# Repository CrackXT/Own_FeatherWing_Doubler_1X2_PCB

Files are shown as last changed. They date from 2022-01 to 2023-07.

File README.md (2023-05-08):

# Own_FeatherWing_Doubler_1X2_PCB

PCB files for two Adafruit Feather/FeatherWing on one PCB (side by side)

# Description

Two Feather/FeatherWing can be placed side by side on this board.

The Doubler 1X2, has a tripple duplicate breakout for each pin on a Feather, as well as a bunch of plain grid development holes. Also, the three sets of pins are cross connected and for GND(- or black) and 3.3V(+ or red), they give you a full strip of connected pads.

The board can be produced here (AISLER) with the files (.brd and .sch) or by any other PCB manufacturer. -> https://aisler.net/

# Serie

- .dev

# Layout

Top<br>
1X2_Top

Bottom<br>
1X2_Bottom

Routing/Dimensions(inch)<br>
1X2_v1 0

Schematic<br>
Schematic as .pdf at the top of the page.

# License

The design and layout is based on open source publications from Adafruit and has been modified for side-by-side assembly.

# Thanks!

Great work and many thanks to Adafruit! https://www.adafruit.com/

# Version - Build

v1.0 - 21.01.2022

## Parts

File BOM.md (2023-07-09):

# BOM - List

part list for Use

# socket strips
2x  1X12  https://www.reichelt.de/buchsenleiste-2-54mm-1x12-gerade-bkl-10120951-p266676.html?&trstct=pol_1&nbc=1<br>
2x  1x16  https://www.reichelt.de/buchsenleiste-2-54mm-1x16-gerade-bkl-10120953-p266678.html?&nbc=1<br>

# pin headers
2x  1X12  https://www.reichelt.de/stiftleiste-2-54mm-1x12-h-11-6mm-gerade-bkl-10120916-p262780.html?&trstct=pol_2&nbc=1<br>
2x  1X16  https://www.reichelt.de/stiftleiste-2-54mm-1x16-h-11-6mm-gerade-bkl-10120918-p262782.html?&trstct=pol_2&nbc=1<br>

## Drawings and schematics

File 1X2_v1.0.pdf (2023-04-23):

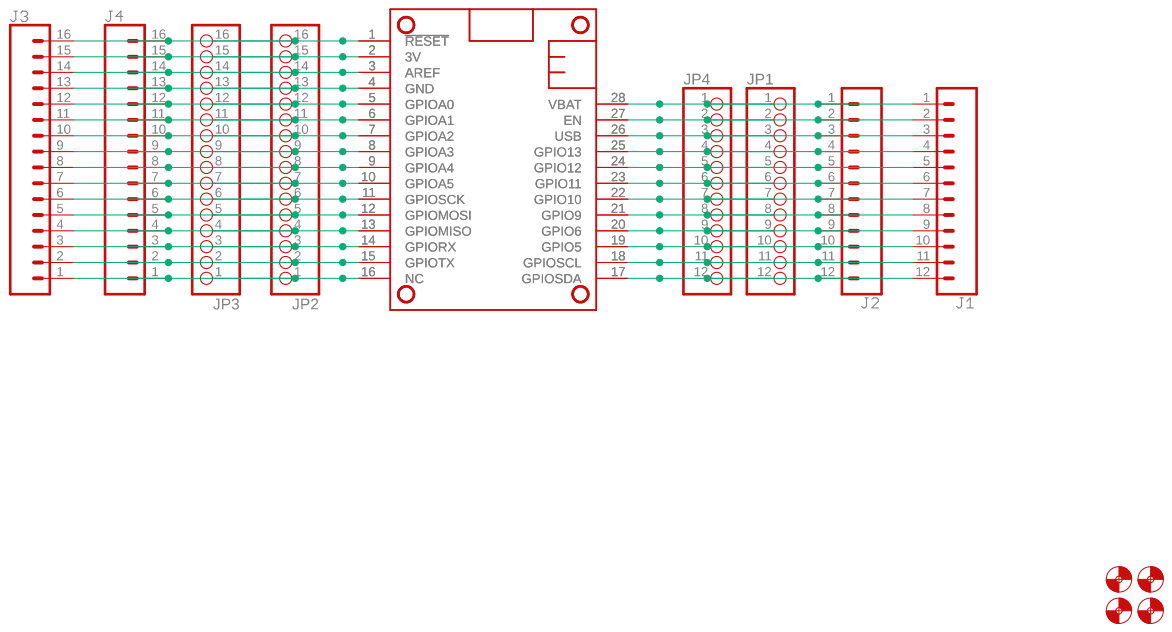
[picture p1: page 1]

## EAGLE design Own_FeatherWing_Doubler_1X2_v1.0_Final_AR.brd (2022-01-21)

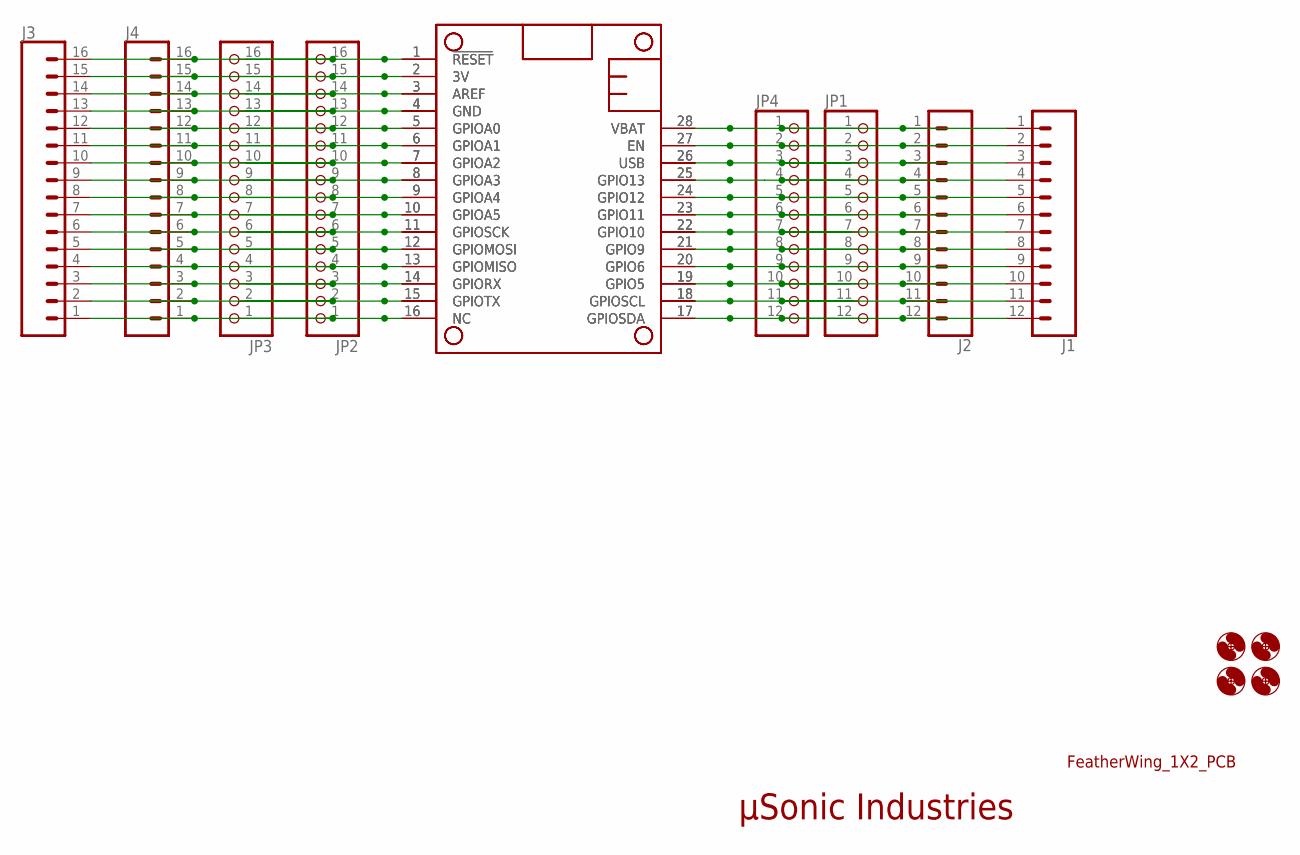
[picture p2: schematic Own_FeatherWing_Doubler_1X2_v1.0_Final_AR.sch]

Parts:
J1, J2: CONN_12NO_SILK; 1X12_NO_SILK
J3, J4: CONN_161X16_NO_SILK; 1X16_NO_SILK
JP1, JP4: HEADER-1X1276MIL; 1X12_ROUND_76MIL
JP2, JP3: HEADER-1X16_76MIL; 1X16_ROUND_76MIL
MS1, MS2: FEATHERWING_NODIM; FEATHERWING_DIM
U$2, U$3, U$4, U$5: MOUNTHOLEBIG; OWN_MOUNTHOLE_BIGAREA

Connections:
3V: J3.15, J4.15, JP2.15, JP3.15, MS1.2 (3V), MS2.2 (3V)
GND: J3.13, J4.13, JP2.13, JP3.13, MS1.4 (GND), MS2.4 (GND)
unnamed: J1.2, J2.2, JP1.2, JP4.2, MS1.27 (EN), MS2.27 (EN)
unnamed: J3.1, J4.1, JP2.1, JP3.1, MS1.16 (NC), MS2.16 (NC)
unnamed: J1.4, J2.4, JP1.4, JP4.4, MS1.25 (GPIO13), MS2.25 (GPIO13)
unnamed: J3.2, J4.2, JP2.2, JP3.2, MS1.15 (GPIOTX), MS2.15 (GPIOTX)
unnamed: J1.5, J2.5, JP1.5, JP4.5, MS1.24 (GPIO12), MS2.24 (GPIO12)
unnamed: J3.3, J4.3, JP2.3, JP3.3, MS1.14 (GPIORX), MS2.14 (GPIORX)
unnamed: J3.4, J4.4, JP2.4, JP3.4, MS1.13 (GPIOMISO), MS2.13 (GPIOMISO)
unnamed: J3.5, J4.5, JP2.5, JP3.5, MS1.12 (GPIOMOSI), MS2.12 (GPIOMOSI)
unnamed: J3.6, J4.6, JP2.6, JP3.6, MS1.11 (GPIOSCK), MS2.11 (GPIOSCK)
unnamed: J3.7, J4.7, JP2.7, JP3.7, MS1.10 (GPIOA5), MS2.10 (GPIOA5)
unnamed: J3.8, J4.8, JP2.8, JP3.8, MS1.9 (GPIOA4), MS2.9 (GPIOA4)
unnamed: J3.9, J4.9, JP2.9, JP3.9, MS1.8 (GPIOA3), MS2.8 (GPIOA3)
unnamed: J3.10, J4.10, JP2.10, JP3.10, MS1.7 (GPIOA2), MS2.7 (GPIOA2)
unnamed: J3.11, J4.11, JP2.11, JP3.11, MS1.6 (GPIOA1), MS2.6 (GPIOA1)
unnamed: J3.12, J4.12, JP2.12, JP3.12, MS1.5 (GPIOA0), MS2.5 (GPIOA0)
unnamed: J3.14, J4.14, JP2.14, JP3.14, MS1.3 (AREF), MS2.3 (AREF)
unnamed: J3.16, J4.16, JP2.16, JP3.16, MS1.1 (!RESET), MS2.1 (!RESET)
unnamed: J1.6, J2.6, JP1.6, JP4.6, MS1.23 (GPIO11), MS2.23 (GPIO11)
unnamed: J1.7, J2.7, JP1.7, JP4.7, MS1.22 (GPIO10), MS2.22 (GPIO10)
unnamed: J1.8, J2.8, JP1.8, JP4.8, MS1.21 (GPIO9), MS2.21 (GPIO9)
unnamed: J1.9, J2.9, JP1.9, JP4.9, MS1.20 (GPIO6), MS2.20 (GPIO6)
unnamed: J1.10, J2.10, JP1.10, JP4.10, MS1.19 (GPIO5), MS2.19 (GPIO5)
unnamed: J1.11, J2.11, JP1.11, JP4.11, MS1.18 (GPIOSCL), MS2.18 (GPIOSCL)
unnamed: J1.12, J2.12, JP1.12, JP4.12, MS1.17 (GPIOSDA), MS2.17 (GPIOSDA)
USB: J1.3, J2.3, JP1.3, JP4.3, MS1.26 (USB), MS2.26 (USB)
VBAT: J1.1, J2.1, JP1.1, JP4.1, MS1.28 (VBAT), MS2.28 (VBAT)

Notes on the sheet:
FeatherWing_1X2_PCB
µSonic Industries

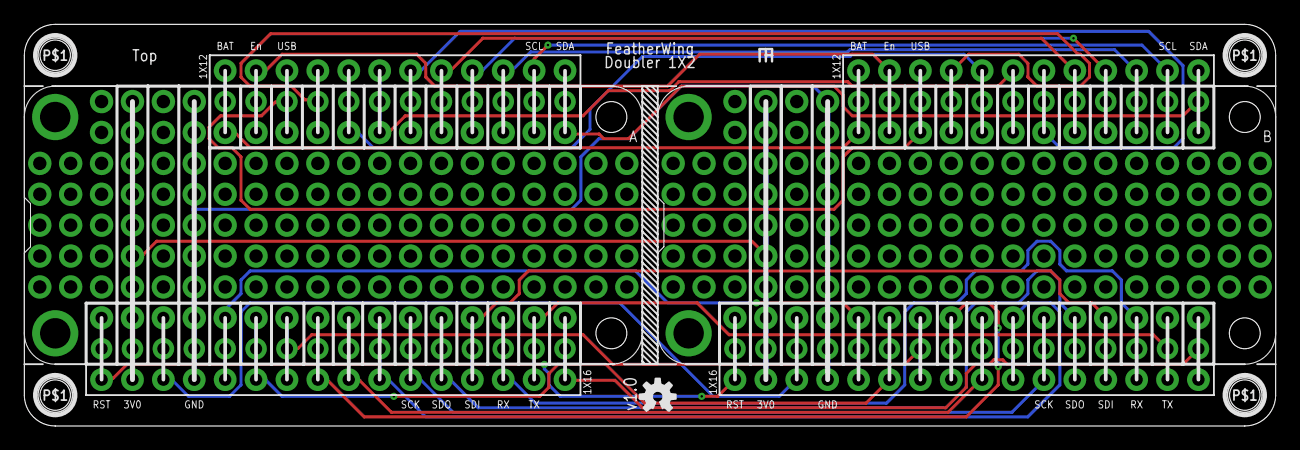
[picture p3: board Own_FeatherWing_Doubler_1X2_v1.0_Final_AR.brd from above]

Board: 2 copper layers, 102.9 x 33.0 mm, 15 parts (0 on the bottom side), 28 nets.

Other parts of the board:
U$6: OSHW-LOGO-S

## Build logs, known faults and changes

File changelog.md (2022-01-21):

# Version - Build
v1.0 - 21.01.2022
- First Release

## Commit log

2022-01-21 Create BOM
2022-01-21 Update BOM

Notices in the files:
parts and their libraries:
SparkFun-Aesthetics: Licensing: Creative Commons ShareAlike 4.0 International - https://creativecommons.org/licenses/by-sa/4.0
